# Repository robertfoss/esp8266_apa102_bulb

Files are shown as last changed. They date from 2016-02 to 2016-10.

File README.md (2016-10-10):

# esp8266_apa102_bulb
ESP8266 based animated APA102 bulbs.

## Render

v4.1: 3D render of the PCB

## Assembly

v4: 95% assembled
v2: Hanging and running over WiFi
v2: Assembled and running over WiFi

## Schematic

v3.1: Schematic

## Changelog

v4.1:
 * Added missing silkscreen
 * Switched from EBC to BEC NPN transistor, to match S8050 part.
 * Changed C7/C8/C10 footprints from 0603->0805
 * Reduced GND pad size of U4 (3.3V LDO)

v4:
 * Reworked inter-pcb connections to minimize gap between leds.
 * Changed APA102 -> GPIO pin mapping.
 * Cost optimized board to fit within 10x10cm envelope.

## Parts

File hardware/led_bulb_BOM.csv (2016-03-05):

Reference | Value | Footprint | Count | Datasheet
LED24 | APA102 | APA102:APA102 | 1 | DOCUMENTATION
LED28 | APA102 | APA102:APA102 | 1 | DOCUMENTATION
LED32 | APA102 | APA102:APA102 | 1 | DOCUMENTATION
LED36 | APA102 | APA102:APA102 | 1 | DOCUMENTATION
LED40 | APA102 | APA102:APA102 | 1 | DOCUMENTATION
LED46 | APA102 | APA102:APA102 | 1 | DOCUMENTATION
LED50 | APA102 | APA102:APA102 | 1 | DOCUMENTATION
LED53 | APA102 | APA102:APA102 | 1 | DOCUMENTATION
LED42 | APA102 | APA102:APA102 | 1 | DOCUMENTATION
LED20 | APA102 | APA102:APA102 | 1 | DOCUMENTATION
LED16 | APA102 | APA102:APA102 | 1 | DOCUMENTATION
LED11 | APA102 | APA102:APA102 | 1 | DOCUMENTATION
LED7 | APA102 | APA102:APA102 | 1 | DOCUMENTATION
LED3 | APA102 | APA102:APA102 | 1 | DOCUMENTATION
LED48 | APA102 | APA102:APA102 | 1 | DOCUMENTATION
LED52 | APA102 | APA102:APA102 | 1 | DOCUMENTATION
LED51 | APA102 | APA102:APA102 | 1 | DOCUMENTATION
LED47 | APA102 | APA102:APA102 | 1 | DOCUMENTATION
LED43 | APA102 | APA102:APA102 | 1 | DOCUMENTATION
LED49 | APA102 | APA102:APA102 | 1 | DOCUMENTATION
LED45 | APA102 | APA102:APA102 | 1 | DOCUMENTATION
U3 | ESP-12E | ESP8266:ESP-12E | 1
R1 | 12k | Resistors_SMD:R_0603 | 1
R2 | 12k | Resistors_SMD:R_0603 | 1
R3 | 12k | Resistors_SMD:R_0603 | 1
R4 | 12k | Resistors_SMD:R_0603 | 1
R5 | 12k | Resistors_SMD:R_0603 | 1
C4 | 100nF | Capacitors_SMD:C_0603 | 1
R6 | 470 | Resistors_SMD:R_0603 | 1
D1 | LED_BLUE | LEDs:LED-0603 | 1
R7 | 470 | Resistors_SMD:R_0603 | 1
SW2 | SW_FLASH | switches:B3F-1050 | 1
R9 | 470 | Resistors_SMD:R_0603 | 1
C8 | 100uF | Capacitors_SMD:C_0603 | 1
U1 | CP2102 | Housings_DFN_QFN:QFN-28-1EP_5x5mm_Pitch0.5mm | 1
C6 | 10uF | Capacitors_SMD:C_0603 | 1
C5 | 100nF | Capacitors_SMD:C_0603 | 1
C2 | 100nF | Capacitors_SMD:C_0603 | 1
C3 | 10uF | Capacitors_SMD:C_0603 | 1
R8 | 470 | Resistors_SMD:R_0603 | 1
P1 | USB_OTG | Connect:USB_Micro-B | 1
U4 | AP1117D33 | TO_SOT_Packages_SMD:SOT-223 | 1
C7 | 22uF | Capacitors_SMD:C_0603 | 1
C10 | 22uF | Capacitors_SMD:C_0603 | 1
SW1 | SW_RST | switches:B3F-1050 | 1
LED12 | APA102 | APA102:APA102 | 1 | DOCUMENTATION
LED8 | APA102 | APA102:APA102 | 1 | DOCUMENTATION
LED4 | APA102 | APA102:APA102 | 1 | DOCUMENTATION
LED9 | APA102 | APA102:APA102 | 1 | DOCUMENTATION
LED5 | APA102 | APA102:APA102 | 1 | DOCUMENTATION
LED1 | APA102 | APA102:APA102 | 1 | DOCUMENTATION
LED10 | APA102 | APA102:APA102 | 1 | DOCUMENTATION
LED6 | APA102 | APA102:APA102 | 1 | DOCUMENTATION
LED2 | APA102 | APA102:APA102 | 1 | DOCUMENTATION
P3 | CONN_01X04 | Connectors:CONN_2.54mm_1x4 | 1
P4 | CONN_01X04 | Connectors:CONN_2.54mm_1x4 | 1
P5 | CONN_01X04 | Connectors:CONN_2.54mm_1x4 | 1
P9 | CONN_01X04 | Connectors:CONN_2.54mm_1x4 | 1
P2 | CONN_01X04 | Connectors:CONN_2.54mm_1x4 | 1
P13 | CONN_01X04 | Connectors:CONN_2.54mm_1x4 | 1
LED23 | APA102 | APA102:APA102 | 1 | DOCUMENTATION
LED27 | APA102 | APA102:APA102 | 1 | DOCUMENTATION
LED31 | APA102 | APA102:APA102 | 1 | DOCUMENTATION
LED35 | APA102 | APA102:APA102 | 1 | DOCUMENTATION
LED39 | APA102 | APA102:APA102 | 1 | DOCUMENTATION
LED19 | APA102 | APA102:APA102 | 1 | DOCUMENTATION
LED15 | APA102 | APA102:APA102 | 1 | DOCUMENTATION
P8 | CONN_01X04 | Connectors:CONN_2.54mm_1x4 | 1
P12 | CONN_01X04 | Connectors:CONN_2.54mm_1x4 | 1
LED22 | APA102 | APA102:APA102 | 1 | DOCUMENTATION
LED26 | APA102 | APA102:APA102 | 1 | DOCUMENTATION
LED30 | APA102 | APA102:APA102 | 1 | DOCUMENTATION
LED34 | APA102 | APA102:APA102 | 1 | DOCUMENTATION
LED38 | APA102 | APA102:APA102 | 1 | DOCUMENTATION
LED18 | APA102 | APA102:APA102 | 1 | DOCUMENTATION
LED14 | APA102 | APA102:APA102 | 1 | DOCUMENTATION
P7 | CONN_01X04 | Connectors:CONN_2.54mm_1x4 | 1
P11 | CONN_01X04 | Connectors:CONN_2.54mm_1x4 | 1
LED21 | APA102 | APA102:APA102 | 1 | DOCUMENTATION
LED25 | APA102 | APA102:APA102 | 1 | DOCUMENTATION
LED29 | APA102 | APA102:APA102 | 1 | DOCUMENTATION
LED33 | APA102 | APA102:APA102 | 1 | DOCUMENTATION
LED37 | APA102 | APA102:APA102 | 1 | DOCUMENTATION
LED17 | APA102 | APA102:APA102 | 1 | DOCUMENTATION
LED13 | APA102 | APA102:APA102 | 1 | DOCUMENTATION
P6 | CONN_01X04 | Connectors:CONN_2.54mm_1x4 | 1
P10 | CONN_01X04 | Connectors:CONN_2.54mm_1x4 | 1
LED44 | APA102 | APA102:APA102 | 1 | DOCUMENTATION
LED41 | APA102 | APA102:APA102 | 1 | DOCUMENTATION
P14 | CONN_01X04 | Connectors:CONN_2.54mm_1x4 | 1
P15 | CONN_01X04 | Connectors:CONN_2.54mm_1x4 | 1
P16 | CONN_01X04 | Connectors:CONN_2.54mm_1x4 | 1
P17 | CONN_01X04 | Connectors:CONN_2.54mm_1x4 | 1

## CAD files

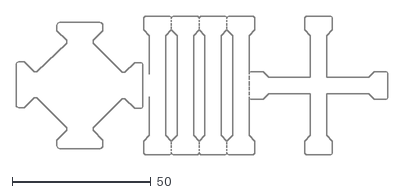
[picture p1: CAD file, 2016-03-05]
hardware/outline/led_bulb_wide_combined.dxf
134.0 x 50.0

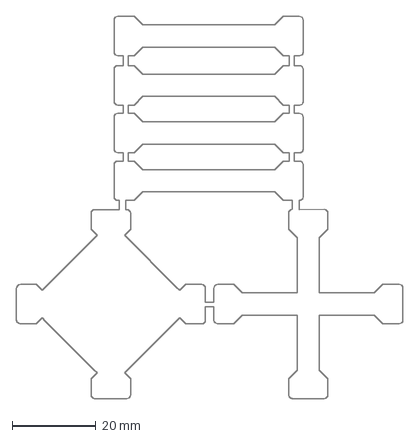
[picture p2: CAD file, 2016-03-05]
hardware/outline/leb_bulb_v4.dxf
92.4 x 91.4 mm

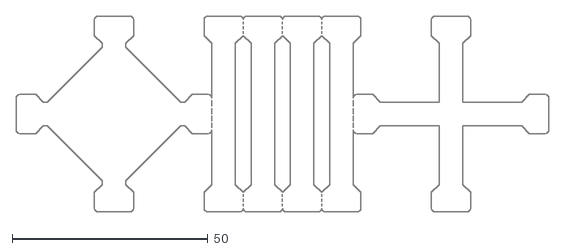
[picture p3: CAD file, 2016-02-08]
hardware/outline/led_bulb_combined.dxf
136.0 x 50.0

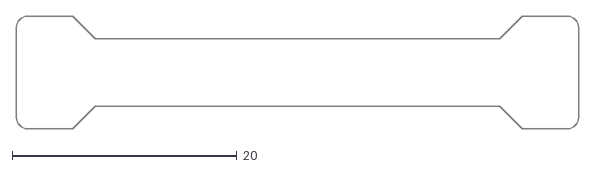
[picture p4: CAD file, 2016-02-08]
hardware/outline/led_bulb_side.dxf
50.0 x 10.0

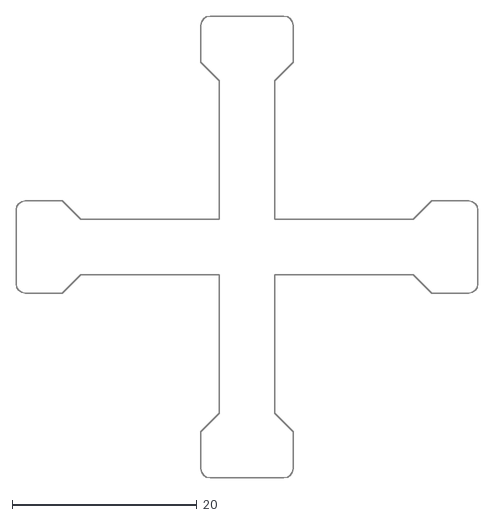
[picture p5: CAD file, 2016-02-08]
hardware/outline/led_bulb_bottom.dxf
50.0 x 50.0

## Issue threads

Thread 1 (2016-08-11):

HW SPI APA102 lib

mkeyno, 2016-08-11:
hi, so sorry to draw issue for my question , actually I'm Arduino user and try to make POV with ESP and APA102 ,however after couple of try , I find current version of FastLED does not support HW SPI for LED chip such as APA102, hence I've tried to look proper lib to drive APA102 on ESP, I really appreciated if you could guide me to proper APA102 lib on ESP can be added in Arduino IDE and support HW SPI?

robertfoss, 2016-08-11:
Hey,

As far as I know there is no HW DMA support for SPI on the ESP8266.

With that being said, do you really need HW SPI? You should be able to run the SPI at 1Mhz.
You should be able to run 125 APA102 leds at 250Hz.
1Mhz / (32bits/led * 250Hz) = 125 leds

mkeyno, 2016-08-11:
yes , it is now  and can get up to 80 MHz, I need to at least 4 to 6 Mbps to run the show and that's why   normal software SPI not work for me ,

robertfoss, 2016-08-11:
I don't think any library currently supports DMA. You could probably make something based on the I2S, which does have DMA support.

Closed 2016-08-11.

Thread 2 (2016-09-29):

APA201 driver End Frames

lorenz24, 2016-09-29:
Hi,
I am wondering whether you could do a change on on your driver.
From my experience, with this APA102, the start frame with 32 x 0x00 is important and works.
But the 32 x 0xff is wrong even the datasheet tells you different.

I found out if you send (32 x 0x00) - n*4Byte (LED data) - (32 x 0x00 plus n/2 x 0x00) the frame will be displayed even you send only one time a frame.

For eg.
150 LEDs on one row and you need to light up only the first 100 LEDs.
You send (32 x 0x00) 100 x 4 Byte (57 x 0x00). Only the frst 100 LEDs are on.

If you send (32 x 0x00) 100 x 4 Byte (32 x 0xff) your 101 LED is on white and the
LEDs are on if you send the second frame.

Conclusion: End Frame (32 + n/2) * 0x00 will allow you sendonlyon times a frame and then+1 LED is off.

robertfoss, 2016-09-29:
That sounds about right?

Have a look at this driver if you're curious about how it can be done:
https://github.com/nodemcu/nodemcu-firmware/blob/master/app/modules/apa102.c

This probably not the right place for further discussion, feel free to reach out to me on dev@memcpy.io.

Closed 2016-09-29.

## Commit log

2016-02-08 Added v3.1 of the hardware.
    [led_bulb-B.Cu.gbl, led_bulb-B.Mask.gbs, led_bulb-B.SilkS.gbo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]
2016-03-05 Added first version of v4 hardware.
    [leb_bulb_v4.dxf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]
2016-03-06 Revised connectors and labels.
    [led_bulb.dsn, led_bulb.kicad_pcb]
2016-03-06 Added missing label.
    [led_bulb.kicad_pcb]
2016-03-06 Rotated bottom footprints to be more intuitive.
    [led_bulb.dsn, led_bulb.kicad_pcb]
2016-03-06 Imported traces and added mouse-bite holes.
    [led_bulb.dsn, led_bulb.kicad_pcb]
2016-03-06 Generated v4 schematic
    [led_bulb-B.Cu.gbl, led_bulb-B.Mask.gbs, led_bulb-B.SilkS.gbo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]
2016-03-13 Added transistor to allow automatic flashing.
    [led_bulb.dsn, led_bulb.kicad_pcb, led_bulb.sch]
2016-03-13 Regenerated v4 gerbers.
    [led_bulb-B.Cu.gbl, led_bulb-B.Mask.gbs, led_bulb-B.SilkS.gbo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]
2016-03-13 Switched to non-plated holes for mouse bites.
    [led_bulb-B.Cu.gbl, led_bulb-B.Mask.gbs, led_bulb-B.SilkS.gbo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]
2016-03-21 Tweaked scripts to make it easier to switch between v2 and v3 HW.
2016-06-12 v4.0 completed.
    [led_bulb-B.Cu.gbr, led_bulb-B.Mask.gbr, led_bulb-B.SilkS.gbr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]
2016-08-13 Reworked sender and receiver side of software.
    - Maintain sockets across animation cycles
    - Added http server to python script as a base for updating
    [led_bulb.kicad_pcb, led_bulb.sch]
2016-08-13 Started work on v4.1 of hardware
    [led_bulb.kicad_pcb, led_bulb.sch]
2016-08-13 Reworked folder structure
    [leb_bulb_v4.dxf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]
2016-08-14 Added support for different types of led bulbs
2016-09-14 Removed debug print
2016-09-17 Rework LedBulb
2016-10-09 Clean up LedBulb string
2016-10-09 Changed U4/C7/C8/C10 footprint sizes
    [led_bulb.kicad_pcb, led_bulb.sch]
2016-10-10 Switch assemly image
2017-01-01 Shorten textual representation of LedBulb
2017-05-28 Switch from pyinotify to watchdog for portability
